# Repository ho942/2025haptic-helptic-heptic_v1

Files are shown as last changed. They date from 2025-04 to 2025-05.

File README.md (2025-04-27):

/// helptic hardware User Manual  ///
- code version: helptic_v1

## 1. Overview

This system measures weight using an HX711 load cell amplifier and provides real-time haptic feedback through two DRV2605L vibration drivers connected via a TCA9548A I2C multiplexer.

Each component must be wired and configured properly for stable operation.

## 2. Components

| No. | Component | Quantity | Description |
|:--:|:---|:---:|:---|
| 1  | Arduino-compatible MCU | 1 | (e.g., Arduino Uno, Mega) |
| 2  | HX711 Module | 1 | Load cell amplifier |
| 3  | Load Cell | 1 | Weight sensor |
| 4  | TCA9548A I2C Multiplexer| 1 | Controls multiple I2C devices |
| 5  | Adafruit DRV2605L Board | 2 | Vibration motor driver |
| 6  | LRA (Linear Resonant Actuator) | 2 | Vibrating motor |
| 7  | Connecting wires | - | Jumper cables |

## 3. Guide to operate

###<1. Required Libraries>
- HX711 Arduino Library
- Adafruit DRV2605 Library

---------------------------------------

###<2. Command Action in the code>

t	Tare (Zero Calibration)

w	Weight Calibration (Input known weight after placing)

ex. write "w1000" if there is 1kg part on the loadcell

a	Start continuous vibration

b	Stop all vibrations and reset count

--------------------------------------

###<3.1 Instruction: how to connect>

1) Connect the arduino to PC

2) Open the arduino ino code and check the port, board for connection

3) Please check whether your PC download the libaries <1.Required Libaries>

4) Upload the Arduino code provided

5) Then connection end.

---------------------------------------

###<3.2 Instruction: how to use>

1)When you upload the code, then loadcell starts to sense so 
   - Press `t` to tare the scale. (for make zero)

2)Then use a known weight 
   - Press `w` to calibrate using a known weight.
ex) if a known weight is 1kg, just put onthe loadcell and then write down on the serial monitor commands like "w1000"

3)For real demo, HMD with AI will detect the hand poster. When AI detect the correct hand poster, PC sends signal for hardware to start CPR. So it starts vibration. Like this, think of 'a' as a signal from PC, but in this code it is trigger by you.
   - Press `a` to start vibration feedback.

4) After that, Pressing the CPR hardware for 30.
   When counts are over than 30, print "c" to Serial and immediately reset count to 0.

5) If you wanna stop, 
   - Press `b` to stop vibrations.
then it show how many press you did. 

---------------------------------------------

###<3.3 What you can change>
- Threshold for counting : The current code is based on 2500g(2kg). Just change the number in the part that says (measured > 2500)
- `a`,`b`,"c" signal: If you wanna integrate hardware to PC, you can use other 'keyword' for starting vibration.

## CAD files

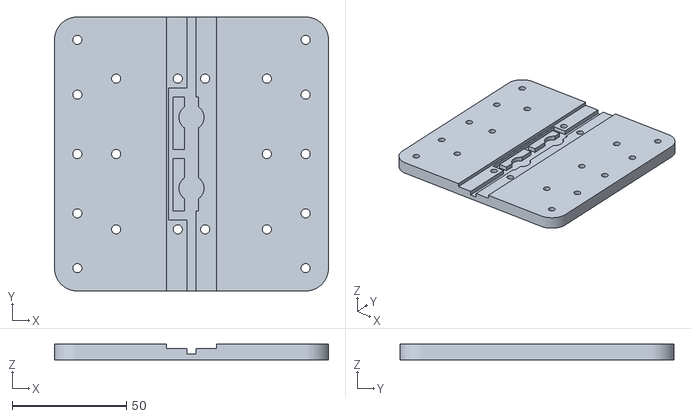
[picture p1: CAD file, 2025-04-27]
helptic_V1_hardware/upper_part_0423.stl
120.0 x 120.0 x 7.00

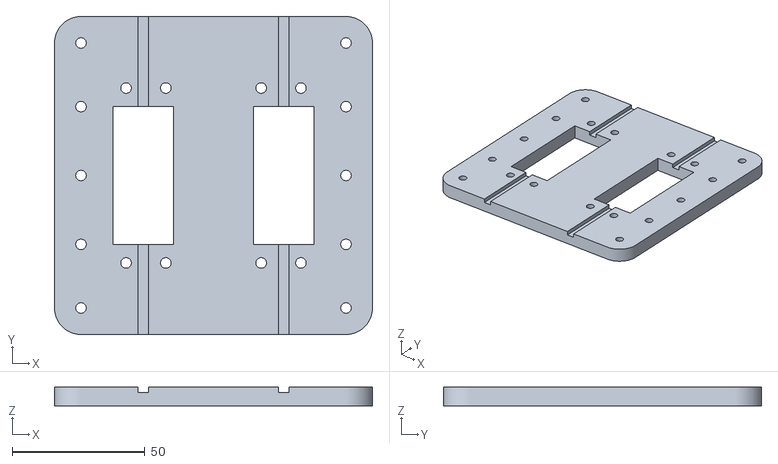
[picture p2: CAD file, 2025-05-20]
helptic_v2/upper_base.stl
120.0 x 120.0 x 7.00

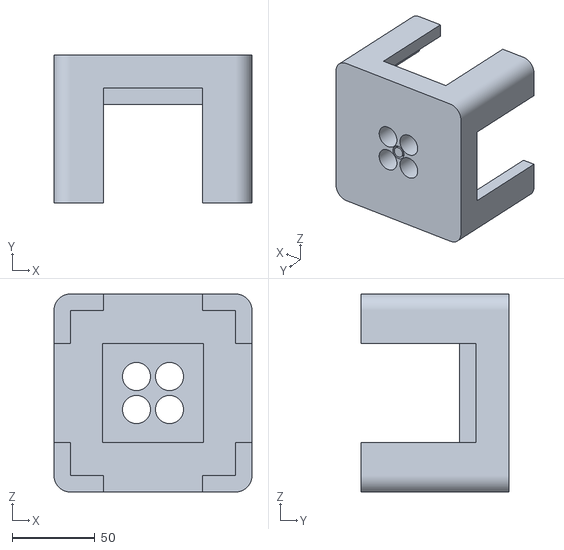
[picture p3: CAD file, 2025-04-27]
helptic_V1_hardware/downpart_fit_250423 (4).stl
120.0 x 90.0 x 120.0

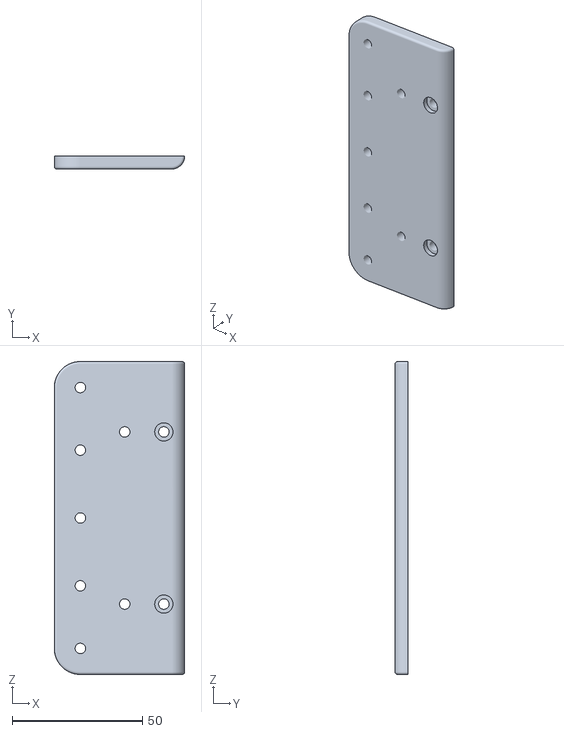
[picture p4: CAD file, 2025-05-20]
helptic_v2/upper_cover.stl
50.0 x 5.00 x 120.0

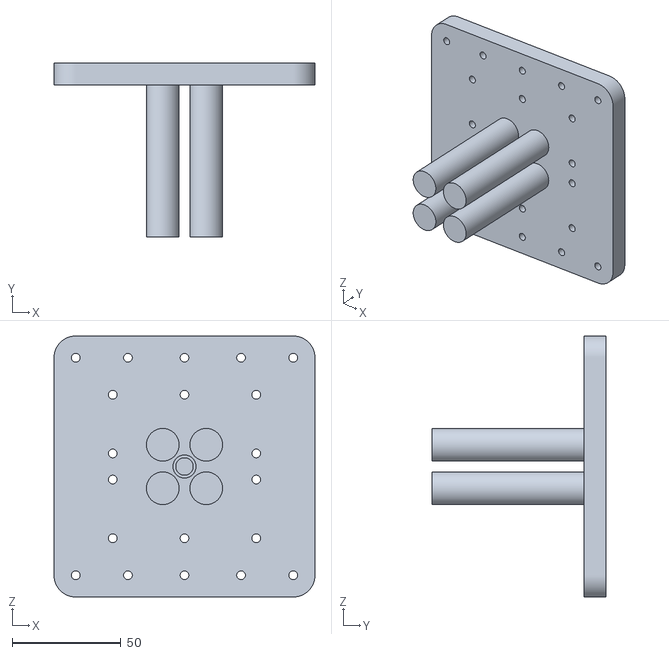
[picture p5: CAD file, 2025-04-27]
helptic_V1_hardware/upper_moving_0422_fit.stl
120.0 x 80.0 x 120.0

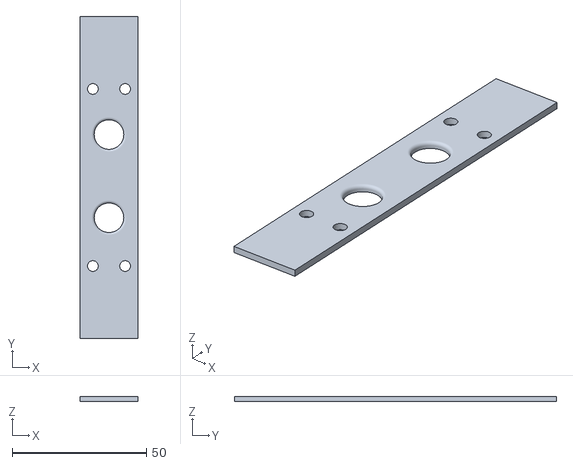
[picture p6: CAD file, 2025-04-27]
helptic_V1_hardware/upper_cover_0423_V2.stl
21.8 x 120.0 x 2.00

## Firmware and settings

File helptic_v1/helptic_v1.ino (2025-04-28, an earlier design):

#include "HX711.h"
#include <Wire.h>
#include "Adafruit_DRV2605.h"

const int DOUT_PIN = 2;
const int SCK_PIN = 3;

HX711 scale;

float calibration_factor = -7050.0;  // Initial calibration factor
bool vibrationActive = false;  // State variable

int count = 0;  // Measurement overrun count
bool overThreshold = false;  // Avoid double counts

// TCA9548A I2C address
#define TCA_ADDR 0x70
Adafruit_DRV2605 drv;

// Function to select TCA9548A channel
void tcaSelect(uint8_t channel) {
  if (channel > 7) return;
  Wire.beginTransmission(TCA_ADDR);
  Wire.write(1 << channel);  // Enable only the selected channel
  Wire.endTransmission();
}

void setup() {
  Serial.begin(115200);
  scale.begin(DOUT_PIN, SCK_PIN);
  scale.set_gain(64); // Set default gain

  scale.set_scale(); // Initialize with no scale factor yet

  Wire.begin();

  // Initialize DRV2605 on each TCA9548A channel
  for (uint8_t i = 0; i < 2; i++) {
    tcaSelect(i);
    if (!drv.begin()) {
      Serial.print("DRV2605 not found on channel ");
      Serial.println(i);
    } else {
      Serial.print("DRV2605 initialized on channel ");
      Serial.println(i);
    }

    drv.selectLibrary(6);  // Library 6 for LRA
    drv.setMode(DRV2605_MODE_INTTRIG);  // Internal trigger
  }

  Serial.println("====== HX711 2-Step Calibration ======");
  Serial.println("[t] -> Tare (Zero Calibration)");
  Serial.println("[w####] -> Weight Calibration (Input known weight after placing it)");
  Serial.println("[a] -> Start continuous vibration pattern");
  Serial.println("[b] -> Stop all vibrations");
  Serial.println("======================================");
}

void loop() {
  scale.set_scale(calibration_factor);
  scale.set_gain(64);
  float measured = scale.get_units(5);

  Serial.print("Measured: ");
  Serial.print(measured);
  Serial.print(" g\tCal.Factor: ");
  Serial.println(calibration_factor);

  int vibrationStrength = 0;

  // Check if vibration should be active
  if (vibrationActive) {
    vibrationStrength = 255;  // Max strength
    if (measured >= 1000) {
      vibrationStrength = map(measured, 1000, 50000, 0, 255);
    }

    if (measured > 2500) {
      if (!overThreshold) {
        count++;
        overThreshold = true;
        if (count > 30) {
          Serial.println("c");
          count = 0;
        }
      }
    } else {
      overThreshold = false;
    }

  } else {
    vibrationStrength = 0;
  }

  int pattern = map(vibrationStrength, 0, 255, 1, 3);
  int repeatDelay = map(vibrationStrength, 0, 255, 200, 50);

  for (uint8_t i = 0; i < 2; i++) {
    tcaSelect(i);

    if (vibrationStrength > 0) {
      drv.setWaveform(0, pattern);
    } else {
      drv.setWaveform(0, 0);
    }

    drv.setWaveform(1, 0);
    drv.go();

    Serial.print("Channel ");
    Serial.print(i);
    Serial.print(" - Pattern executed with vibration strength: ");
    Serial.print(vibrationStrength);
    Serial.print(" and pattern: ");
    Serial.println(pattern);

    delay(repeatDelay);
  }

  // Handle user input
  if (Serial.available()) {
    String input = Serial.readStringUntil('\n');
    input.trim();  // Remove whitespace

    if (input.startsWith("w")) {
      String weightStr = input.substring(1);
      float actualWeight = weightStr.toFloat();

      if (actualWeight > 0) {
        Serial.println("→ Calibrating with known weight: " + String(actualWeight) + " grams...");
        float measuredWeight = scale.get_units(10);
        calibration_factor = calibration_factor * (measuredWeight / actualWeight);
        Serial.print("✔ Calibration complete. New factor: ");
        Serial.println(calibration_factor);
      } else {
        Serial.println("✖ Invalid weight input after 'w'. Try again.");
      }
    }
    else if (input == "t") {
      Serial.println("→ Taring... Remove all weight.");
      delay(2000);
      scale.tare();
      Serial.println("✔ Tare complete. Scale is zeroed.");
    }
    else if (input == "a") {
      vibrationActive = true;
      count = 0;
      Serial.println("→ Continuous vibration pattern started.");
    }
    else if (input == "b") {
      vibrationActive = false;
      Serial.print("→ Vibration stopped. Count was: ");
      Serial.println(count);
      count = 0;
      Serial.println("→ All vibrations stopped.");
    }
    else {
      Serial.println("✖ Unknown command.");
    }
  }

  delay(10);  // Small loop delay
}

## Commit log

2025-04-27 Update and rename helptic_v1 to stl file for 3d print
2025-04-27 3d stl file
    [downpart_fit_250423 (4).stl, upper_cover_0423_V2.stl, upper_moving_0422_fit.stl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]
2025-04-28 Update helptic_v1.ino
    There was an issue in the previous code where calibration was not working.
    [helptic_v1.ino]
2025-05-20 hardware for v2
    When we pushed the hardware_v1 hard, it didn't vibrate well because there was no space for LRA to vibrate. So we moved the position of part that vibrate to upper palm that contact to hand. So it delivered vibration well.
    [upper_base.stl, upper_cover.stl]
